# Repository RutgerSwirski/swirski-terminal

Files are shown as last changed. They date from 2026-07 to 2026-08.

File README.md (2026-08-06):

# Swirski Terminal

Swirski Terminal is a small wearable terminal built around an ESP32-S3,
an ILI9341 display, LVGL, and a rotary encoder. An Android companion app sends
notifications, media state, time, and Wi-Fi configuration over an encrypted
BLE connection.

The shared C++ application can also run as an SDL desktop build for faster UI
development and protocol testing.

## Current Features

- Notification snapshots, live notifications, detail views, and toasts
- Music state, progress, play/pause, previous, and next controls
- BLE pairing, bonding, chunked messages, and automatic reconnection
- Wi-Fi scanning, connection management, signal status, and internet testing
- Phone-synchronized date and time with persistent fallback
- Rotary encoder navigation, virtual keyboard, settings, and optional screen timeout
- Automatic Wi-Fi and BLE reconnection after transient disconnects
- Pong and Blackjack
- Shared LVGL screens and services across ESP32 and desktop targets

## Repository Layout

```text
app/      Shared C++ application, screens, services, protocol, and UI
desktop/  SDL/LVGL desktop simulator and C++ tests
esp32/    ESP-IDF firmware, hardware input, display, Wi-Fi, and BLE transport
mobile/   React Native Android companion app
docs/     Protocol documentation
```

## Desktop Build

Requirements:

- CMake 3.22 or newer
- Ninja
- A C++20 compiler
- SDL2 development files

Build and launch the simulator from the repository root:

```bash
./buildDesktop.sh
```

Run the C++ tests after building:

```bash
ctest --test-dir desktop/build --output-on-failure
```

## ESP32 Build

The firmware currently targets an ESP32-S3 with 4 MB flash, an ILI9341
320x240 SPI display, a rotary encoder, and a back button. Hardware pins are
defined near the top of `esp32/main/main.cpp` and in `esp32/main/inputs/`.
The display backlight uses an inverted BC327 PWM stage on GPIO 12. Brightness
can be adjusted from 10–100% in 10% steps in Settings, is retained across
restarts, and the backlight switches off with the display timeout.
The 30-second screen sleep can also be disabled in Settings to keep the display
on, and that choice is retained across restarts.
Settings also provides confirmed reboot and power-off actions. Power-off uses
ESP32 deep sleep because the current hardware has no software-controlled load
switch; press either the rotary knob or back button to start it again.

The MAX17048 fuel gauge is read at I2C address `0x36` every five seconds.
For the current direct-GPIO prototype, connect it as follows:

- MAX17048 SDA to ESP32-S3 GPIO 1
- MAX17048 SCL to ESP32-S3 GPIO 2
- MAX17048 VIN to 3.3 V and GND to GND

The two JST-PH battery sockets on the breakout are a pass-through pair: connect
the single-cell LiPo to either socket and the terminal's power/charging path to
the other. Battery voltage is retained in system state as millivolts, charge
percentage is shown in the status bar, and both readings are logged at debug
level. The PCB-v1 schematic instead reserves GPIO 8/9 for its shared I2C bus;
those pins must not be selected in this prototype firmware while the back and
encoder switches still use direct GPIO.

Install ESP-IDF, then build from the `esp32` directory:

```bash
source "$HOME/.espressif/v6.0.2/esp-idf/export.sh"
idf.py build
```

Flash and monitor a connected device:

```bash
idf.py -p /dev/ttyACM0 -b 115200 flash monitor
```

Change the serial port when your device appears under a different path.

Pushes to `main` that change `app/` or `esp32/` automatically build the
firmware and update the `firmware-latest` GitHub Release. The release asset is
published as `swirski_os_esp32.bin` for the terminal's OTA updater. The same
workflow can also be started manually from the GitHub Actions page.

## Android Companion

Requirements:

- Node.js 22.11 or newer
- Android Studio and the Android SDK
- A physical Android device with Bluetooth Low Energy

Install dependencies and start Metro:

```bash
cd mobile
npm install
npm start
```

In another terminal, install the debug app:

```bash
cd mobile
npm run android
```

Android notification-listener access is required for notification sync and
media discovery. The app prompts for the relevant Bluetooth and notification
permissions when needed.

Pushes to `main` that change `mobile/` automatically build the Android app and
replace the rolling `mobile-latest` GitHub Release. The app checks that
release's small manifest when it opens and shows **Mobile update available**
when its installed build number is older. The download opens in Android's
normal APK installation flow.

The rolling workflow requires the same permanent signing key for every build so
Android can install each APK over the previous one. Reuse and securely back up
the key that signed any APK already installed on your phone. Only generate a
new key if there is no existing release key:

```bash
keytool -genkeypair -v \
  -keystore swirski-upload.jks \
  -alias swirski-upload \
  -keyalg RSA \
  -keysize 2048 \
  -validity 10000
```

Configure these repository secrets before running the workflow, replacing the
example path with the existing key when applicable:

```bash
base64 -w 0 path/to/swirski-upload.jks | gh secret set SWIRSKI_UPLOAD_KEYSTORE_BASE64
gh secret set SWIRSKI_UPLOAD_STORE_PASSWORD
gh secret set SWIRSKI_UPLOAD_KEY_ALIAS
gh secret set SWIRSKI_UPLOAD_KEY_PASSWORD
```

Use the alias entered above (`swirski-upload` in the example). The last three
commands prompt for their values. Never commit the key or passwords. Losing
the key means future APKs cannot update existing installations.

Local standalone builds made by `mobile/deploy.sh` use Android's development
key unless the same `SWIRSKI_UPLOAD_*` environment variables are supplied. If
the app currently installed on a phone uses that development key, uninstall it
once before installing the first `mobile-latest` APK, then re-enable Android's
notification-listener access. Subsequent rolling releases install as updates.

## Protocol

Messages use a versioned JSON envelope. Larger BLE messages are divided into
frames and reassembled by the receiver. See
[`docs/ble-framing.md`](docs/ble-framing.md) for the framing format.

## License

This project is available under the [MIT License](LICENSE).

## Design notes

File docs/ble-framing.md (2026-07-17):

# Swirski BLE Framing

## Purpose

BLE can only send a limited number of bytes in a single write or notification.

Swirski protocol messages may be larger than this limit, especially notification messages containing titles, body text, or other data.

BLE framing splits one complete JSON message into smaller chunks before sending it.

The receiver then joins the chunks back together before passing the complete JSON to the Swirski protocol parser.

```text
JSON message
    ↓
UTF-8 bytes
    ↓
split into BLE frames
    ↓
send frames
    ↓
reassemble frames
    ↓
complete JSON message
```

The shared Swirski protocol should never receive partial chunks.

---

## Terminology

### Message

A complete UTF-8 JSON protocol message.

Example:

```json
{
  "version": 1,
  "type": "ping",
  "id": "mobile-123"
}
```

### Frame

One small BLE packet containing:

- A framing header
- A section of the complete message

### Transfer

The process of sending one complete message using one or more frames.

---

## Frame format

Each BLE frame begins with an eight-byte header.

| Bytes | Field | Type | Description |
| ----- | --- | --- | --- |
| 0 | Magic | `uint8` | Constant `0x53` |
| 1 | Frame version | `uint8` | Current value is `1` |
| 2–5 | Transfer ID | `uint32`  | Identifies the current transfer |
| 6 | Chunk index | `uint8` | Position of this chunk, starting at `0` |
| 7 | Chunk count | `uint8` | Total number of chunks in the transfer  |
| 8+ | Payload | Raw bytes | Part of the UTF-8 JSON message |

Multi-byte integers use little-endian byte order.

Example transfer ID:

```text
Transfer ID: 42
Hex value:   0x0000002A
Wire bytes:  2A 00 00 00
```

---

## Example

Assume a message is too large and must be split into two chunks.

The transfer ID is `42`.

### First frame

```text
53 01 2A 00 00 00 00 02 [first section of JSON]
│  │  │           │  │
│  │  │           │  └── total chunks: 2
│  │  │           └───── chunk index: 0
│  │  └───────────────── transfer ID: 42
│  └──────────────────── frame version: 1
└─────────────────────── magic byte: 0x53
```

### Second frame

```text
53 01 2A 00 00 00 01 02 [remaining section of JSON]
│  │  │           │  │
│  │  │           │  └── total chunks: 2
│  │  │           └───── chunk index: 1
│  │  └───────────────── transfer ID: 42
│  └──────────────────── frame version: 1
└─────────────────────── magic byte: 0x53
```

After both frames arrive, the receiver joins the payload bytes:

```text
first section + remaining section
```

The result is the original complete JSON message.

---

## Sending rules

For the first implementation:

1. Only one message is sent at a time in each direction.
2. Chunks are sent in order.
3. Chunk indexes start at `0`.
4. The sender waits for each BLE write to finish before sending the next chunk.
5. All chunks in one transfer use the same transfer ID.
6. All chunks in one transfer use the same chunk count.

Example:

```text
Send chunk 0
→ wait for write to finish
Send chunk 1
→ wait for write to finish
Transfer complete
```

Messages must not be interleaved.

Valid:

```text
Message A chunk 0
Message A chunk 1
Message B chunk 0
Message B chunk 1
```

Not supported initially:

```text
Message A chunk 0
Message B chunk 0
Message A chunk 1
Message B chunk 1
```

---

## Receiving rules

A received frame is grouped by BLE connection and transfer ID.

When a chunk arrives, the receiver stores:

- Transfer ID
- Expected chunk count
- Received payload bytes by chunk index
- Received payload byte count

Each chunk in the same transfer must have:

- The same chunk count
- A chunk index lower than the chunk count

Example:

```text
Received chunk: 1
→ store payload at index 1
```

If the chunk count changes:

```text
Expected chunks: 2
Received chunks: 3
→ reject and reset transfer
```

The message is complete when all chunk indexes from `0` to `chunk count - 1` have arrived.

Only then should the receiver:

1. Join all payload bytes in chunk-index order
2. Convert the bytes into a UTF-8 string
3. Pass the string to the shared protocol parser

```text
BLE frames
→ complete UTF-8 JSON
→ handleIncomingMessage()
```

---

## Chunk size

The maximum characteristic value size is approximately:

```text
negotiated MTU - 3
```

The Swirski framing header uses eight bytes.

Therefore:

```text
maximum chunk payload = negotiated MTU - 3 - 8
```

Example with an MTU of `128`:

```text
128 byte MTU
- 3 byte ATT overhead
- 8 byte Swirski frame header
= 117 message bytes per chunk
```

The exact negotiated MTU should be used when creating frames.

---

## Message encoding

Complete protocol messages use UTF-8 JSON.

The sender must:

```text
JSON string
→ UTF-8 bytes
→ split bytes into chunks
```

The receiver must:

```text
reassemble bytes
→ decode complete UTF-8 string
→ parse JSON
```

Chunks must be split by byte position, not by JavaScript character position.

This prevents multi-byte characters such as emoji from being damaged.

---

## Transfer ID

The BLE transfer ID is separate from the protocol message ID.

BLE transfer ID:

```text
Used to identify chunks belonging to one BLE transfer
```

Protocol message ID:

```json
{
  "id": "message-123"
}
```

The protocol ID cannot be used for framing because it is inside the JSON and is not available until the complete message has been reconstructed.

The transfer ID is a `uint32` value and wraps back to `1` after `4294967295`.

---

## Timeouts

Incomplete transfers must not remain in memory forever.

If no new chunk arrives within three seconds, the receiver discards the partial transfer.

```text
Chunk received
→ start or refresh timeout

No chunk for 3 seconds
→ reset transfer
```

A partial transfer should also be cleared when:

- The BLE connection closes
- The chunk count changes within an existing transfer
- The message exceeds the maximum allowed size

---

## Limits

Initial framing limits:

| Limit | Value |
| --- | --- |
| Header size | 8 bytes |
| Maximum chunks | 255 |
| Maximum complete message | 64 KiB |
| Incomplete transfer timeout | 3 seconds |
| Concurrent incoming transfers | By connection and transfer ID |

The practical maximum is also limited by the negotiated MTU because a complete
message may use at most 255 chunks.

---

## Direction

The same framing format is used in both directions.

### Phone to terminal

```text
React Native
→ split JSON into frames
→ write frames to RX characteristic
→ ESP32 reassembles message
```

### Terminal to phone

```text
ESP32
→ split JSON into frames
→ notify frames through TX characteristic
→ React Native reassembles message
```

Each direction maintains its own transfer state.

---

## Version 1 scope

The first version supports:

- Ordered chunks
- One outgoing transfer at a time
- UTF-8 JSON messages
- Transfer timeouts
- Maximum message size validation
- Framing in both directions

The first version does not include:

- Interleaved outgoing transfers
- Retransmission
- Checksums
- Compression
- Multiple simultaneous outgoing messages

These features can be added later if they become necessary.

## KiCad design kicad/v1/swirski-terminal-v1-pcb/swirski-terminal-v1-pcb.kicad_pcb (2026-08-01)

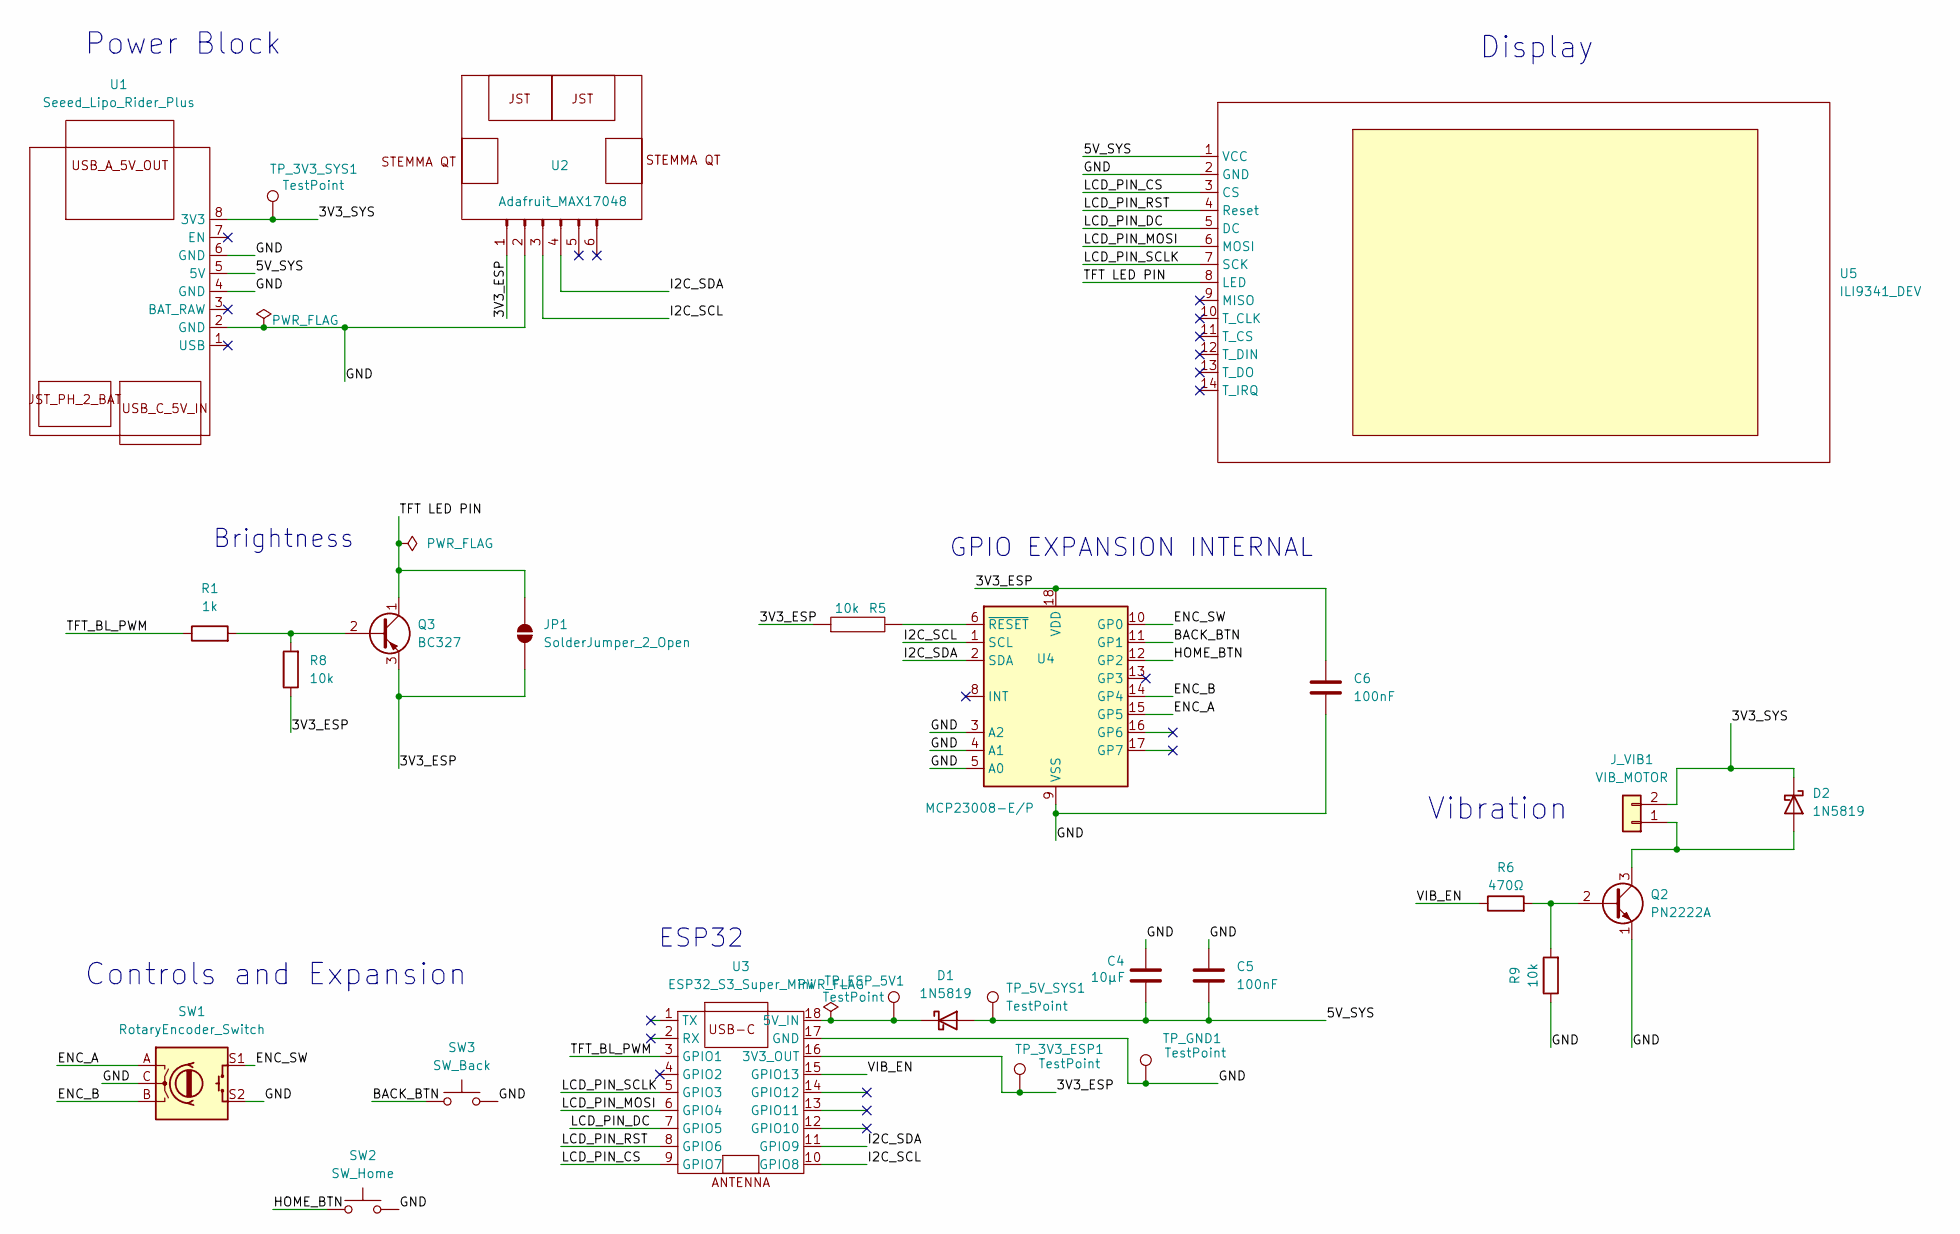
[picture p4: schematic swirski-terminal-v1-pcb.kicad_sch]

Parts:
C4: 10µF; CP_Radial_D5.0mm_P2.00mm
C5, C6: 100nF; C_Disc_D5.0mm_W2.5mm_P5.00mm
D1, D2: 1N5819; D_DO-41_SOD81_P10.16mm_Horizontal
JP1: SolderJumper_2_Open; PinHeader_1x02_P2.54mm_Vertical
J_VIB1: VIB_MOTOR; PinHeader_1x02_P2.54mm_Vertical
Q2: PN2222A; TO-92_Inline
Q3: BC327; TO-92_Inline
R1: 1k; R_Axial_DIN0207_L6.3mm_D2.5mm_P10.16mm_Horizontal
R5, R8, R9: 10k; R_Axial_DIN0207_L6.3mm_D2.5mm_P10.16mm_Horizontal
R6: 470Ω; R_Axial_DIN0207_L6.3mm_D2.5mm_P10.16mm_Horizontal
SW1: RotaryEncoder_Switch; RotaryEncoder_Alps_EC11E-Switch_Vertical_H20mm
SW2: SW_Home; SW_PUSH_6mm
SW3: SW_Back; SW_PUSH_6mm
TP_3V3_ESP1, TP_3V3_SYS1, TP_5V_SYS1: TestPoint; TestPoint_Loop_D2.50mm_Drill1.0mm
TP_ESP_5V1: TestPoint; TestPoint_Loop_D2.50mm_Drill1.0mm
TP_GND1: TestPoint; TestPoint_Loop_D2.50mm_Drill1.0mm
U1: Seeed_Lipo_Rider_Plus; Seeed_LiPo_Rider_Plus
U2: Adafruit_MAX17048; Adafruit_MAX17048_Breakout
U3: ESP32_S3_Super_Mini; ESP32_S3_SUPER_MINI_2x09Pins
U4: MCP23008-E/P; DIP-18_W7.62mm
U5: ILI9341_DEV; ILI9341_DEV_14Pin

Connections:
/3V3_ESP: C6.1, JP1.1 (A), Q3.3 (E), R5.1, R8.1, TP_3V3_ESP1.1 (1_1), U2.1 (VIN), U3.16 (3V3_OUT), U4.18 (VDD)
/3V3_SYS: D2.1 (K), J_VIB1.2, TP_3V3_SYS1.1 (1_1), U1.8 (3V3)
/5V_SYS: C4.2, C5.2, D1.2 (A), TP_5V_SYS1.1 (1_1), U1.5 (5V), U5.1 (VCC)
/BACK_BTN: SW3.1, U4.11 (GP1)
/ENC_A: SW1.A, U4.15 (GP5)
/ENC_B: SW1.B, U4.14 (GP4)
/ENC_SW: SW1.S1, U4.10 (GP0)
/EXTRA_GPIO_1: U4.13 (GP3)
/GND: C4.1, C5.1, C6.2, Q2.1 (E), R9.1, SW1.C, SW1.S2, SW2.2, SW3.2, TP_GND1.1 (1_1), U1.2 (GND), U1.4 (GND), U1.6 (GND), U2.2 (GND), U3.17 (GND), U4.3 (A2), U4.4 (A1), U4.5 (A0), U4.9 (VSS), U5.2 (GND)
/HOME_BTN: SW2.1, U4.12 (GP2)
/I2C_SCL: U2.3 (SCL), U3.10 (GPIO8), U4.1 (SCL)
/I2C_SDA: U2.4 (SDA), U3.11 (GPIO9), U4.2 (SDA)
/LCD_PIN_CS: U3.9 (GPIO7), U5.3 (CS)
/LCD_PIN_DC: U3.7 (GPIO5), U5.5 (DC)
/LCD_PIN_MOSI: U3.6 (GPIO4), U5.6 (MOSI)
/LCD_PIN_RST: U3.8 (GPIO6), U5.4 (Reset)
/LCD_PIN_SCLK: U3.5 (GPIO3), U5.7 (SCK)
/TFT LED PIN: JP1.2 (B), Q3.1 (C), U3.4 (GPIO2), U5.8 (LED)
/TFT_BL_PWM: R1.1, U3.3 (GPIO1)
/VIB_EN: R6.1, U3.15 (GPIO13)
unnamed: D1.1 (K), TP_ESP_5V1.1 (1_1), U3.18 (5V_IN)
unnamed: D2.2 (A), J_VIB1.1, Q2.3 (C)
unnamed: Q2.2 (B), R6.2, R9.2
unnamed: Q3.2 (B), R1.2, R8.2
unnamed: R5.2, U4.6 (~RESET)

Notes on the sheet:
Power Block
Controls and Expansion
Vibration
Display
ESP32
GPIO EXPANSION INTERNAL
Brightness

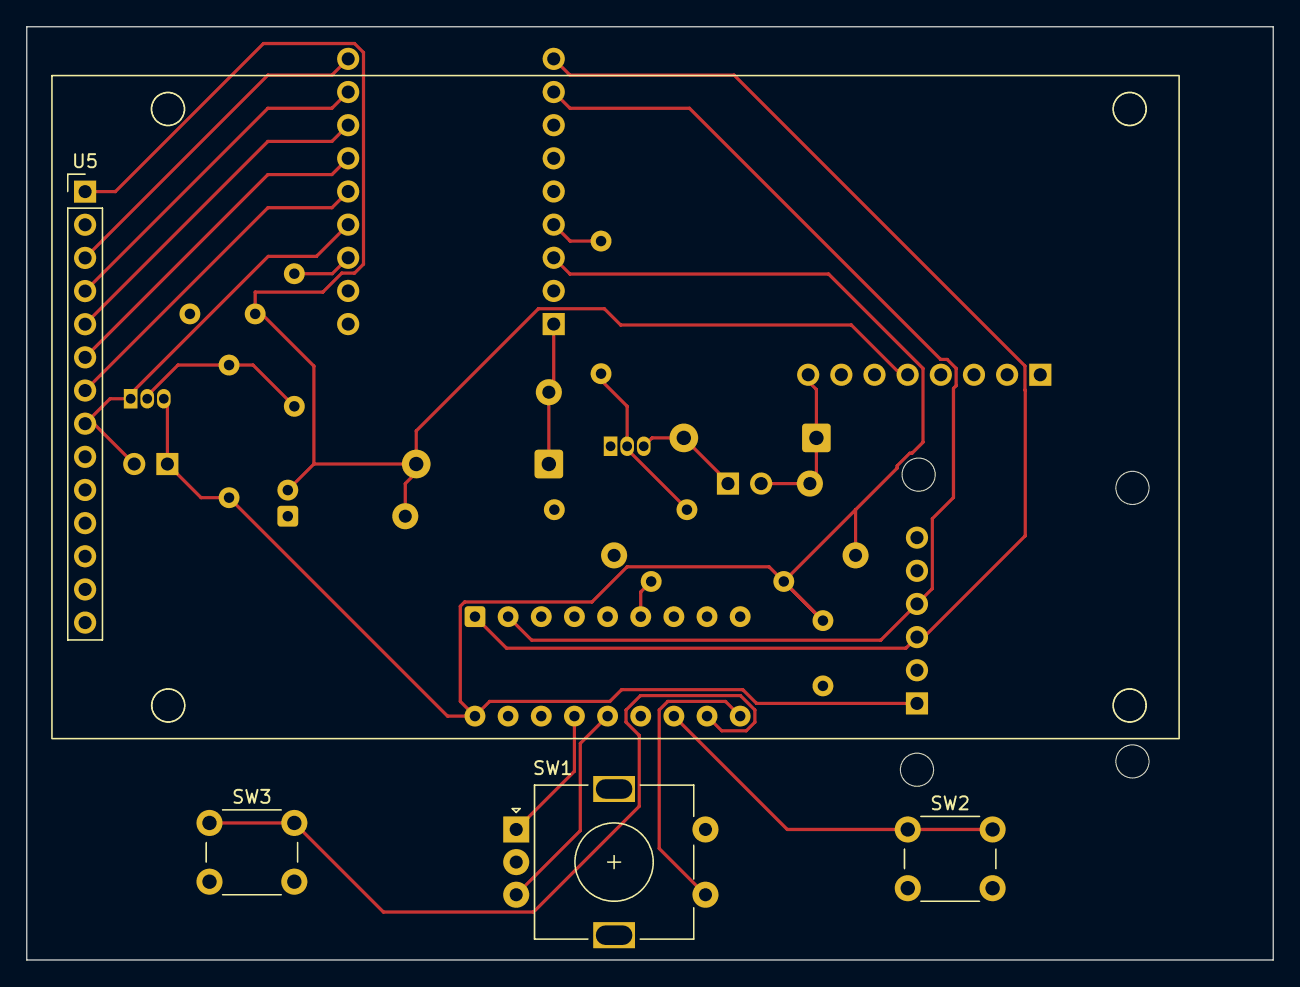
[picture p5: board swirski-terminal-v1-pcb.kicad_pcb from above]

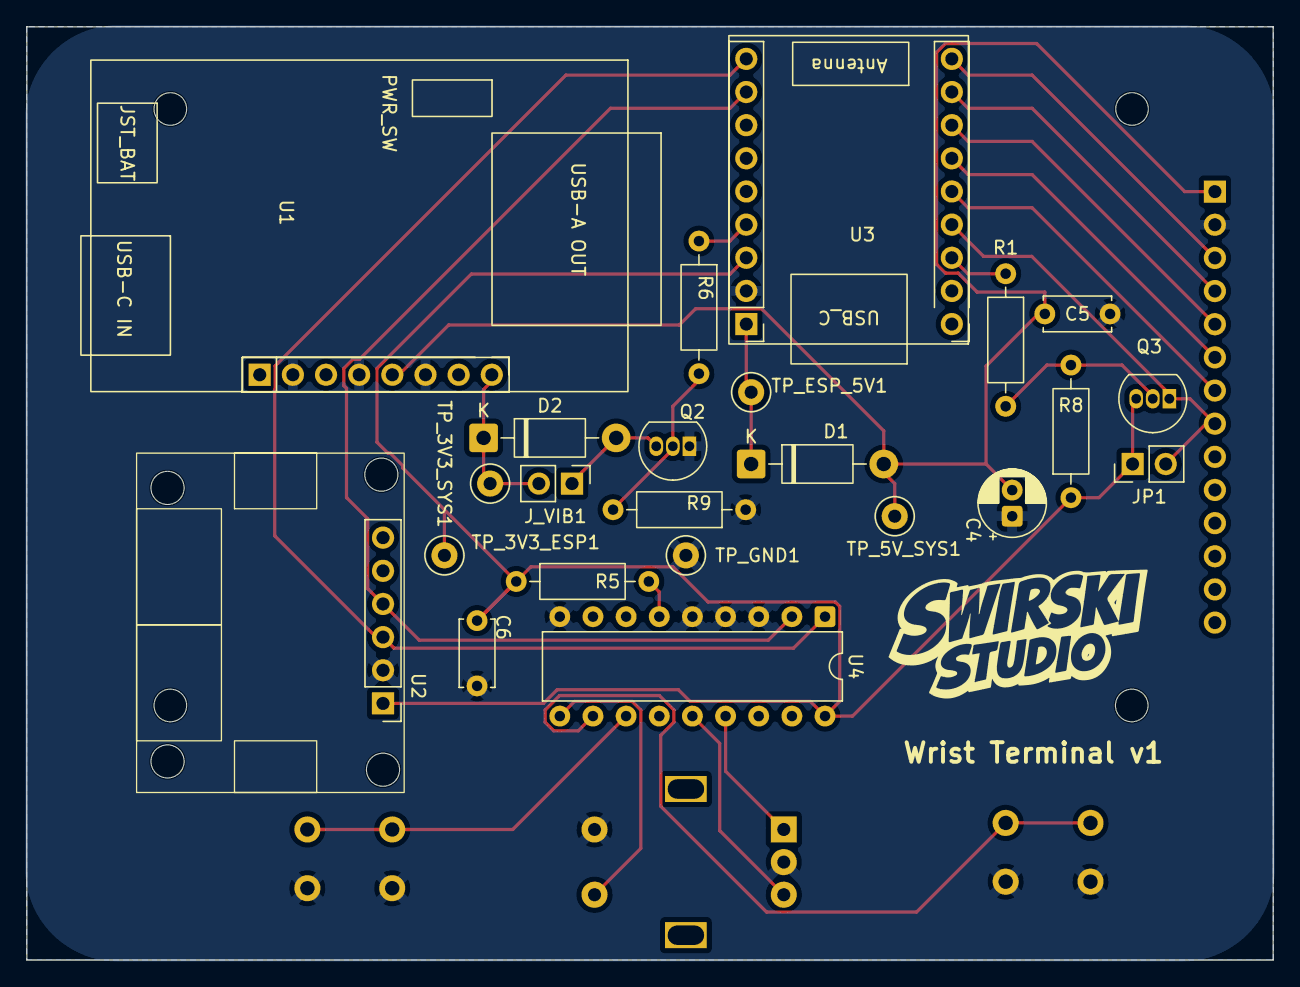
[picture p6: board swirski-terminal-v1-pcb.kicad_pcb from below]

Board: 2 copper layers, 95.5 x 71.5 mm, 27 parts (23 on the bottom side), 24 nets.

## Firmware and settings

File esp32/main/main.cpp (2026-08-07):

#include "driver/spi_master.h"
#include "esp_err.h"
#include "esp_lcd_panel_io.h"
#include "esp_lcd_panel_ops.h"
#include "esp_lcd_ili9341.h"
#include "esp_log.h"
#include "esp_lvgl_port.h"
#include "esp_sleep.h"
#include "esp_wifi.h"
#include "nvs_flash.h"
#include "freertos/FreeRTOS.h"
#include "freertos/task.h"
#include "lvgl.h"
#include "driver/gpio.h"

#include <cstdint>
#include <optional>

#include "app.hpp"
#include "./inputs/rotary_encoder.hpp"
#include "./inputs/push_buttons.hpp"
#include "haptics.hpp"
#include "app_constants.hpp"
#include "services/date_time.hpp"
#include "services/device_control.hpp"
#include "services/settings_service.hpp"
#include "services/firmware_update.hpp"
#include "screen_manager.hpp"
#include "settings_screen.hpp"
#include "notifications_screen.hpp"
#include "notification_screen.hpp"
#include "music_screen.hpp"
#include "weather_screen.hpp"
#include "ui/status_bar.hpp"
#include "ui/notification_toast.hpp"
#include "input.hpp"
#include "hardware_settings.hpp"
#include "wifi_service.hpp"
#include "wifi_screen.hpp"
#include "protocol.hpp"
#include "system_state.hpp"
#include "max17048.hpp"
#include "backlight.hpp"

#include "ble_transport.hpp"

namespace
{

    constexpr spi_host_device_t LCD_HOST = SPI2_HOST;

    constexpr gpio_num_t LCD_PIN_MOSI = GPIO_NUM_6;
    constexpr gpio_num_t LCD_PIN_SCLK = GPIO_NUM_7;
    constexpr gpio_num_t LCD_PIN_CS = GPIO_NUM_5;
    constexpr gpio_num_t LCD_PIN_DC = GPIO_NUM_4;
    constexpr gpio_num_t LCD_PIN_RST = GPIO_NUM_3;
    constexpr gpio_num_t BACK_BUTTON_PIN = GPIO_NUM_8;
    constexpr gpio_num_t ROTARY_BUTTON_PIN = GPIO_NUM_9;

    constexpr int LCD_WIDTH = 320;
    constexpr int LCD_HEIGHT = 240;

    lv_display_t *displayHandle = nullptr;
    esp_lcd_panel_handle_t panelHandle = nullptr;

    void setDisplayPower(bool on)
    {
        swirski::hardware::backlight::setEnabled(on);

        if (panelHandle != nullptr)
        {
            esp_lcd_panel_disp_on_off(
                panelHandle,
                on);
        }
    }

    void playNotificationHaptic()
    {
        swirski::hardware::haptics::play(
            swirski::hardware::haptics::Effect::Notification);
    }
}

void initialiseDisplay()
{
    constexpr size_t drawBufferHeight = 20;

    const size_t transferBufferSize =
        LCD_WIDTH *
        drawBufferHeight *
        sizeof(uint16_t);

    ESP_LOGI(swirski::TAG, "Initialising SPI bus");

    spi_bus_config_t busConfig{};

    busConfig.sclk_io_num = LCD_PIN_SCLK;
    busConfig.mosi_io_num = LCD_PIN_MOSI;
    busConfig.miso_io_num = -1;
    busConfig.quadwp_io_num = -1;
    busConfig.quadhd_io_num = -1;
    busConfig.max_transfer_sz =
        static_cast<int>(transferBufferSize);

    ESP_ERROR_CHECK(
        spi_bus_initialize(
            LCD_HOST,
            &busConfig,
            SPI_DMA_CH_AUTO));

    ESP_LOGI(swirski::TAG, "Creating LCD SPI interface");

    esp_lcd_panel_io_handle_t ioHandle = nullptr;

    esp_lcd_panel_io_spi_config_t ioConfig{};

    ioConfig.cs_gpio_num = LCD_PIN_CS;
    ioConfig.dc_gpio_num = LCD_PIN_DC;
    ioConfig.spi_mode = 0;
    ioConfig.pclk_hz = 40 * 1000 * 1000;
    ioConfig.trans_queue_depth = 10;
    ioConfig.lcd_cmd_bits = 8;
    ioConfig.lcd_param_bits = 8;

    ESP_ERROR_CHECK(
        esp_lcd_new_panel_io_spi(
            static_cast<esp_lcd_spi_bus_handle_t>(LCD_HOST),
            &ioConfig,
            &ioHandle));

    ESP_LOGI(swirski::TAG, "Creating ILI9341 panel");

    esp_lcd_panel_dev_config_t panelConfig{};

    panelConfig.reset_gpio_num = LCD_PIN_RST;
    panelConfig.rgb_ele_order = LCD_RGB_ELEMENT_ORDER_BGR;
    panelConfig.bits_per_pixel = 16;

    ESP_ERROR_CHECK(
        esp_lcd_new_panel_ili9341(
            ioHandle,
            &panelConfig,
            &panelHandle));

    ESP_ERROR_CHECK(esp_lcd_panel_reset(panelHandle));
    ESP_ERROR_CHECK(esp_lcd_panel_init(panelHandle));
    ESP_ERROR_CHECK(esp_lcd_panel_disp_on_off(panelHandle, true));

    ESP_LOGI(swirski::TAG, "Registering display with LVGL");

    lvgl_port_display_cfg_t displayConfig{};

    displayConfig.io_handle = ioHandle;
    displayConfig.panel_handle = panelHandle;
    displayConfig.buffer_size = LCD_WIDTH * drawBufferHeight;
    displayConfig.double_buffer = false;
    displayConfig.hres = LCD_WIDTH;
    displayConfig.vres = LCD_HEIGHT;
    displayConfig.monochrome = false;

    displayConfig.rotation.swap_xy = true;
    displayConfig.rotation.mirror_x = true;
    displayConfig.rotation.mirror_y = true;

    displayConfig.color_format = LV_COLOR_FORMAT_RGB565;

    displayConfig.flags.buff_dma = true;
    displayConfig.flags.swap_bytes = true;

    displayHandle = lvgl_port_add_disp(&displayConfig);

    if (displayHandle == nullptr)
    {
        ESP_LOGE(swirski::TAG, "Could not register display with LVGL");
        return;
    }

    ESP_LOGI(swirski::TAG, "Display initialised");
}

// use C linkage
extern "C" void app_main()
{
    ESP_LOGI(swirski::TAG, "Starting Swirski OS");

    swirski::hardware::backlight::initialise();

    esp_err_t nvsResult =
        nvs_flash_init();

    if (
        nvsResult == ESP_ERR_NVS_NO_FREE_PAGES ||
        nvsResult == ESP_ERR_NVS_NEW_VERSION_FOUND)
    {
        ESP_ERROR_CHECK(
            nvs_flash_erase());

        nvsResult =
            nvs_flash_init();
    }

    ESP_ERROR_CHECK(nvsResult);

    const lvgl_port_cfg_t lvglConfig =
        ESP_LVGL_PORT_INIT_CONFIG();

    ESP_ERROR_CHECK(
        lvgl_port_init(&lvglConfig));

    vTaskDelay(1);

    initialiseDisplay();

    swirski::screens::manager::setDisplayPowerHandler(
        setDisplayPower);

    swirski::service::settings::initialise();
    swirski::settings::hardware::initialise();
    swirski::services::wifi_service::initialise();

    vTaskDelay(1);

    swirski::inputs::rotary_encoder::initialise();
    swirski::inputs::push_buttons::initialise();

    swirski::hardware::haptics::initialise();
    swirski::hardware::max17048::initialise();

    swirski::service::date_time::initialise(0);

    swirski::transport::ble::BleTransport bleTransport;

    bleTransport.initialise();
    swirski::services::device_control::setRestartHandler(
        [&bleTransport]()
        {
            bleTransport.disconnectAll();
            vTaskDelay(pdMS_TO_TICKS(250));
            esp_restart();
        });
    swirski::services::device_control::setPowerOffHandler(
        [&bleTransport]()
        {
            bleTransport.disconnectAll();
            setDisplayPower(false);
            esp_wifi_stop();

            while (
                gpio_get_level(BACK_BUTTON_PIN) == 0 ||
                gpio_get_level(ROTARY_BUTTON_PIN) == 0)
            {
                vTaskDelay(pdMS_TO_TICKS(10));
            }

            const std::uint64_t wakeButtonMask =
                (1ULL << BACK_BUTTON_PIN) |
                (1ULL << ROTARY_BUTTON_PIN);

            ESP_ERROR_CHECK(
                esp_sleep_enable_ext1_wakeup_io(
                    wakeButtonMask,
                    ESP_EXT1_WAKEUP_ANY_LOW));

            vTaskDelay(pdMS_TO_TICKS(250));
            esp_deep_sleep_start();
        });
    swirski::services::firmware_update::setBeforeRestartHandler(
        [&bleTransport]()
        {
            bleTransport.disconnectAll();
        });
    swirski::screens::music_screen::setTransport(
        &bleTransport);

    vTaskDelay(1);

    if (lvgl_port_lock(0))
    {
        swirski::app::createInterface(displayHandle);

        swirski::ui::status_bar::updateClock();

        lvgl_port_unlock();
    }

    swirski::services::firmware_update::confirmRunningFirmware();

    vTaskDelay(1);

    bool wifiScanInProgress = false;
    auto lastWifiState =
        swirski::services::wifi_service::getConnectionState();
    auto lastInternetTestState =
        swirski::services::wifi_service::getInternetTestState();
    std::optional<std::uint8_t> lastSentBatteryPercent;
    bool lastSentCharging = false;
    bool batteryStatusSent = false;

    swirski::services::notification_service::setAlertHandler(
        playNotificationHaptic);

    while (true)
    {

        bleTransport.update();
        swirski::services::wifi_service::update();
        swirski::hardware::max17048::update();

        const auto systemSnapshot =
            swirski::state::system::getSnapshot();

        if (
            systemSnapshot.connection.status !=
            swirski::state::system::ConnectionStatus::Connected)
        {
            batteryStatusSent = false;
        }
        else if (
            !batteryStatusSent ||
            systemSnapshot.batteryPercent !=
                lastSentBatteryPercent ||
            systemSnapshot.charging != lastSentCharging)
        {
            bleTransport.send(
                swirski::protocol::createBatteryStatusMessage());

            lastSentBatteryPercent =
                systemSnapshot.batteryPercent;
            lastSentCharging =
                systemSnapshot.charging;
            batteryStatusSent = true;
        }

        const bool wifiScanning =
            swirski::services::wifi_service::isScanning();
        const auto wifiState =
            swirski::services::wifi_service::getConnectionState();
        const auto internetTestState =
            swirski::services::wifi_service::getInternetTestState();
        bool wifiStatusSent = false;

        if (wifiScanning)
        {
            wifiScanInProgress = true;
        }
        else if (wifiScanInProgress)
        {
            wifiScanInProgress = false;
            bleTransport.send(
                swirski::protocol::createWifiNetworksMessage());
            bleTransport.send(
                swirski::protocol::createWifiStatusMessage());
            wifiStatusSent = true;
        }

        if (wifiState != lastWifiState)
        {
            lastWifiState = wifiState;

            if (!wifiStatusSent)
            {
                bleTransport.send(
                    swirski::protocol::createWifiStatusMessage());
            }
        }

        if (internetTestState != lastInternetTestState)
        {
            lastInternetTestState = internetTestState;

            if (
                internetTestState ==
                    swirski::services::wifi_service::InternetTestState::Success ||
                internetTestState ==
                    swirski::services::wifi_service::InternetTestState::Failed)
            {
                bleTransport.send(
                    swirski::protocol::createWifiStatusMessage());
            }
        }

        if (lvgl_port_lock(0))
        {
            swirski::ui::status_bar::updateSystemState();
            swirski::ui::notification_toast::update();
            swirski::screens::manager::updatePowerState();

            if (
                swirski::screens::manager::getCurrentScreen() ==
                swirski::screens::manager::Screen::Notifications)
            {
                swirski::screens::notifications_screen::
                    refreshIfNeeded();
            }

            if (
                swirski::screens::manager::getCurrentScreen() ==
                swirski::screens::manager::Screen::Notification)
            {
                swirski::screens::notification_screen::
                    refreshIfNeeded();
            }

            if (
                swirski::screens::manager::getCurrentScreen() ==
                swirski::screens::manager::Screen::Music)
            {
                swirski::screens::music_screen::
                    refreshIfNeeded();
            }

            if (
                swirski::screens::manager::getCurrentScreen() ==
                swirski::screens::manager::Screen::Weather)
            {
                swirski::screens::weather_screen::refreshIfNeeded();
            }

            if (
                swirski::screens::manager::getCurrentScreen() ==
                swirski::screens::manager::Screen::Wifi)
            {
                swirski::screens::wifi_screen::refreshIfNeeded();
            }

            if (
                swirski::screens::manager::getCurrentScreen() ==
                swirski::screens::manager::Screen::Settings)
            {
                swirski::screens::settings_screen::refreshIfNeeded();
            }

            lvgl_port_unlock();
        }

        swirski::inputs::rotary_encoder::poll();

        swirski::hardware::haptics::update();

        if (swirski::inputs::push_buttons::backPressed())
        {
            ESP_LOGI(swirski::TAG, "Back button pressed");

            if (lvgl_port_lock(20))
            {
                const bool screenWoke =
                    swirski::screens::manager::wake();

                const bool toastDismissed =
                    !screenWoke &&
                    swirski::ui::notification_toast::dismiss();

                if (!screenWoke && !toastDismissed)
                {
                    swirski::input::handleInput(
                        swirski::input::input_action::Back);
                }

                lvgl_port_unlock();
            }
        }

        if (swirski::service::date_time::update())
        {
            if (lvgl_port_lock(20))
            {
                swirski::ui::status_bar::updateClock();
                lvgl_port_unlock();
            }
        }

        vTaskDelay(1);
    }
}

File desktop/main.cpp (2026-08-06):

#define SDL_MAIN_HANDLED

#include "lvgl.h"
#include "app.hpp"

#include <SDL2/SDL.h>

#include <iostream>

#include "inputs/keyboard.hpp"

#include "services/date_time.hpp"

#include "ui/status_bar.hpp"

#include <chrono>

#include <ctime>

#include "websocket_transport.hpp"
#include "music_screen.hpp"
#include "weather_screen.hpp"
#include "notifications_screen.hpp"
#include "notification_screen.hpp"
#include "screen_manager.hpp"
#include "settings_screen.hpp"
#include "wifi_screen.hpp"

int main()

{

    SDL_Event event;

    bool running = true;

    lv_init();

    lv_display_t *display =
        lv_sdl_window_create(320, 240);

    lv_sdl_window_set_zoom(display, 2.0f);

    if (display == nullptr)
    {
        return 1;
    }

    lv_display_set_default(display);

    lv_sdl_mouse_create();
    lv_sdl_mousewheel_create();
    lv_sdl_keyboard_create();

    swirski::app::createInterface(display);

    const auto now = std::chrono::system_clock::now();

    const std::time_t currentTime =
        std::chrono::system_clock::to_time_t(now);

    swirski::service::date_time::initialise(currentTime);
    swirski::ui::status_bar::updateClock();

    swirski::transport::websocket::WebSocketTransport websocketTransport;

    // initialise transport websocket
    websocketTransport.initialise();
    swirski::screens::music_screen::setTransport(
        &websocketTransport);

    while (running)
    {

        websocketTransport.update();
        swirski::ui::status_bar::updateSystemState();

        switch (swirski::screens::manager::getCurrentScreen())
        {
        case swirski::screens::manager::Screen::Notifications:
            swirski::screens::notifications_screen::refreshIfNeeded();
            break;
        case swirski::screens::manager::Screen::Notification:
            swirski::screens::notification_screen::refreshIfNeeded();
            break;
        case swirski::screens::manager::Screen::Music:
            swirski::screens::music_screen::refreshIfNeeded();
            break;
        case swirski::screens::manager::Screen::Weather:
            swirski::screens::weather_screen::refreshIfNeeded();
            break;
        case swirski::screens::manager::Screen::Wifi:
            swirski::screens::wifi_screen::refreshIfNeeded();
            break;
        case swirski::screens::manager::Screen::Settings:
            swirski::screens::settings_screen::refreshIfNeeded();
            break;
        default:
            break;
        }

        swirski::inputs::keyboard::processInput(event, running);

        const bool time_changed = swirski::service::date_time::update();

        if (time_changed)
        {
            swirski::ui::status_bar::updateClock();
        }

        lv_timer_handler();
        lv_delay_ms(5);
    }

    return 0;
}

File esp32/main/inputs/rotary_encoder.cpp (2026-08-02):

// ESP32 rotary encoder GPIO setup and input decoding
#include "driver/gpio.h"
#include "driver/pulse_cnt.h"
#include "esp_log.h"
#include "esp_lvgl_port.h"

#include <cstdint>

#include "rotary_encoder.hpp"
#include "app_constants.hpp"
#include "input.hpp"
#include "haptics.hpp"

namespace swirski::inputs::rotary_encoder
{

    namespace
    {
        constexpr gpio_num_t ROTARY_PIN_A = GPIO_NUM_11;
        constexpr gpio_num_t ROTARY_PIN_B = GPIO_NUM_10;
        constexpr gpio_num_t ROTARY_SWITCH = GPIO_NUM_9;

        constexpr int PCNT_LOW_LIMIT = -32'767;
        constexpr int PCNT_HIGH_LIMIT = 32'767;
        constexpr int PULSES_PER_DETENT = 4;
        constexpr int MAX_PENDING_DETENTS = 4;
        constexpr std::uint32_t PCNT_GLITCH_FILTER_NS = 10'000;

        pcnt_unit_handle_t pcntUnit = nullptr;
        pcnt_channel_handle_t pcntChannelA = nullptr;
        pcnt_channel_handle_t pcntChannelB = nullptr;

        int previousPulseCount = 0;
        int pendingPulseCount = 0;
        int prevSwitch = 0;

        bool dispatchInput(
            swirski::input::input_action action,
            const char *message)
        {
            if (!lvgl_port_lock(20))
            {
                return false;
            }

            ESP_LOGD(swirski::TAG, "%s", message);

            swirski::input::handleInput(action);

            lvgl_port_unlock();

            swirski::hardware::haptics::play(
                swirski::hardware::haptics::Effect::Tick);

            return true;
        }

    }

    void initialise()
    {
        ESP_LOGI(swirski::TAG, "Initialising rotary encoder");

        gpio_config_t rotaryConfig{};

        rotaryConfig.pin_bit_mask =
            (1ULL << ROTARY_PIN_A) |
            (1ULL << ROTARY_PIN_B) |
            (1ULL << ROTARY_SWITCH);

        rotaryConfig.mode = GPIO_MODE_INPUT;
        rotaryConfig.pull_up_en = GPIO_PULLUP_ENABLE;
        rotaryConfig.pull_down_en = GPIO_PULLDOWN_DISABLE;
        rotaryConfig.intr_type = GPIO_INTR_DISABLE;

        ESP_ERROR_CHECK(gpio_config(&rotaryConfig));

        pcnt_unit_config_t unitConfig{};
        unitConfig.low_limit = PCNT_LOW_LIMIT;
        unitConfig.high_limit = PCNT_HIGH_LIMIT;

        ESP_ERROR_CHECK(
            pcnt_new_unit(
                &unitConfig,
                &pcntUnit));

        pcnt_glitch_filter_config_t glitchFilterConfig{};
        glitchFilterConfig.max_glitch_ns =
            PCNT_GLITCH_FILTER_NS;

        ESP_ERROR_CHECK(
            pcnt_unit_set_glitch_filter(
                pcntUnit,
                &glitchFilterConfig));

        pcnt_chan_config_t channelAConfig{};
        channelAConfig.edge_gpio_num = ROTARY_PIN_A;
        channelAConfig.level_gpio_num = ROTARY_PIN_B;

        ESP_ERROR_CHECK(
            pcnt_new_channel(
                pcntUnit,
                &channelAConfig,
                &pcntChannelA));

        pcnt_chan_config_t channelBConfig{};
        channelBConfig.edge_gpio_num = ROTARY_PIN_B;
        channelBConfig.level_gpio_num = ROTARY_PIN_A;

        ESP_ERROR_CHECK(
            pcnt_new_channel(
                pcntUnit,
                &channelBConfig,
                &pcntChannelB));

        ESP_ERROR_CHECK(
            pcnt_channel_set_edge_action(
                pcntChannelA,
                PCNT_CHANNEL_EDGE_ACTION_DECREASE,
                PCNT_CHANNEL_EDGE_ACTION_INCREASE));

        ESP_ERROR_CHECK(
            pcnt_channel_set_level_action(
                pcntChannelA,
                PCNT_CHANNEL_LEVEL_ACTION_KEEP,
                PCNT_CHANNEL_LEVEL_ACTION_INVERSE));

        ESP_ERROR_CHECK(
            pcnt_channel_set_edge_action(
                pcntChannelB,
                PCNT_CHANNEL_EDGE_ACTION_INCREASE,
                PCNT_CHANNEL_EDGE_ACTION_DECREASE));

        ESP_ERROR_CHECK(
            pcnt_channel_set_level_action(
                pcntChannelB,
                PCNT_CHANNEL_LEVEL_ACTION_KEEP,
                PCNT_CHANNEL_LEVEL_ACTION_INVERSE));

        ESP_ERROR_CHECK(
            pcnt_unit_enable(pcntUnit));

        ESP_ERROR_CHECK(
            pcnt_unit_clear_count(pcntUnit));

        ESP_ERROR_CHECK(
            pcnt_unit_start(pcntUnit));

        previousPulseCount = 0;
        pendingPulseCount = 0;
        prevSwitch = gpio_get_level(ROTARY_SWITCH);

        ESP_LOGI(swirski::TAG, "Rotary encoder initialised");
    }

    void poll()
    {
        int pulseCount = 0;

        ESP_ERROR_CHECK(
            pcnt_unit_get_count(
                pcntUnit,
                &pulseCount));

        int pulseDelta =
            pulseCount -
            previousPulseCount;

        if (pulseDelta > PCNT_HIGH_LIMIT / 2)
        {
            pulseDelta -= PCNT_HIGH_LIMIT;
        }
        else if (pulseDelta < PCNT_LOW_LIMIT / 2)
        {
            pulseDelta -= PCNT_LOW_LIMIT;
        }

        pendingPulseCount += pulseDelta;

        const int maxPendingPulses =
            PULSES_PER_DETENT *
            MAX_PENDING_DETENTS;

        if (pendingPulseCount > maxPendingPulses)
        {
            pendingPulseCount = maxPendingPulses;
        }
        else if (pendingPulseCount < -maxPendingPulses)
        {
            pendingPulseCount = -maxPendingPulses;
        }

        previousPulseCount = pulseCount;

        if (pendingPulseCount >= PULSES_PER_DETENT)
        {
            if (dispatchInput(
                    swirski::input::input_action::Next,
                    "NEXT"))
            {
                pendingPulseCount -= PULSES_PER_DETENT;
            }
        }
        else if (pendingPulseCount <= -PULSES_PER_DETENT)
        {
            if (dispatchInput(
                    swirski::input::input_action::Previous,
                    "PREVIOUS"))
            {
                pendingPulseCount += PULSES_PER_DETENT;
            }
        }

        const int currentSwitch = gpio_get_level(ROTARY_SWITCH);

        // Detect the button changing from not pressed to pressed.
        if (prevSwitch == 1 && currentSwitch == 0)
        {
            dispatchInput(
                swirski::input::input_action::Confirm,
                "CONFIRM");
        }

        prevSwitch = currentSwitch;
    }
}

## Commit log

2026-07-11 added rotary encoder and clean build and flash to esp32
2026-07-11 setup rotary encoder logic!
2026-07-11 rotary encoder working!
2026-07-14 Add push buttons input handling: implement initialization and back button press detection; update main and CMakeLists to integrate functionality
2026-07-15 Add ArduinoJson dependency and implement message handling in protocol
2026-07-16 Enhance Bluetooth connection handling: add connection status management and improve device connection logic
2026-07-16 Add locking mechanism around status bar update to ensure thread safety
2026-07-17 Refactor BLE message framing: update header structure, implement frame assembler, and enhance message handling
2026-07-17 Add frame queuing and sending mechanism in BLE transport
2026-07-17 Implement time synchronization feature: add TimeSync message type and send current date/time from mobile app
2026-07-17 Refactor BLE frame logging: introduce shouldLogFrameProgress function for consistent logging and update notification toast duration to 4500ms
2026-07-17 Refactor UI components: enhance ConnectionPanel, DebugActions, and DeviceList with Card components and improve layout in TerminalScreen
2026-07-17 Add settings screen and power management: implement settings UI, input handling, and power mode management
2026-07-18 Filter devices based on connection status: show only connected device when one is selected
2026-07-18 Persist time and power settings
2026-07-18 Expand ESP32 application partition
    [partitions.csv]
2026-07-18 Add ESP32 Wi-Fi setup flow
2026-07-18 Implement send retry mechanism for BLE frames and update SDK configuration
2026-07-18 Configure dual-slot OTA rollback
    [partitions.csv]
2026-07-19 Refactor Snake and Tetris screens for improved memory management and game logic
    - Introduced lazy allocation of board buffers in both Snake and Tetris screens to optimize memory usage.
    - Added functions to allocate, pause, and resume game timers for better control over game state.
    - Enhanced collision detection logic in Snake to prevent game over when the snake eats food.
    - Improved food placement logic in Snake to avoid infinite loops when the board is nearly full.
    - Updated drawing functions to ensure proper rendering of game elements.
    - Refactored game initialization and cleanup processes to ensure proper resource management.
    - Added error handling for memory allocation failures in both g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
2026-07-23 Enhance Snake and Tetris screens for ESP32 compatibility and memory management
2026-07-26 Add initial files for Swirski Terminal PCB project
    - Created fp-lib-table for footprint library management.
    - Added main PCB file (swirski-terminal-v1-pcb.kicad_pcb) with versioning.
    - Included project settings in swirski-terminal-v1-pcb.kicad_prl.
    - Established design settings and rules in swirski-terminal-v1-pcb.kicad_pro.
    - Created schematic file (swirski-terminal-v1-pcb.kicad_sch) with basic structure.
    - Added symbol library table (sym-lib-table) for component management.
    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
    [swirski-terminal-v1-pcb.kicad_pcb, swirski-terminal-v1-pcb.kicad_sch]
2026-07-27 Add Swirski_Terminal library to symbol library table
    [swirski-terminal-v1-pcb.kicad_sch]
2026-07-27 updated swirski terminal schematic!
    [swirski-terminal-v1-pcb.kicad_sch]
2026-07-28 PCB Updates
    [swirski-terminal-v1-pcb.kicad_sch]
2026-07-29 More Kicad updates - playing around with the schematic and replacing SMD components that were being used on the PCB
    [swirski-terminal-v1-pcb.kicad_pcb, swirski-terminal-v1-pcb.kicad_sch]
2026-08-01 Add lock file for KiCad schematic to prevent concurrent edits
    [swirski-terminal-v1-pcb-B_Cu.gbr, swirski-terminal-v1-pcb-B_Mask.gbr, swirski-terminal-v1-pcb-B_Paste.gbr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]
2026-08-02 feat(rotary_encoder): enhance rotary encoder input handling with pulse counter and dispatch logic
2026-08-02 feat(haptics): enhance haptic feedback with notification phases and motor control
2026-08-03 chore(kicad): keep local history out of repository
2026-08-04 feat(battery): integrate MAX17048 fuel gauge for battery monitoring
2026-08-06 fix(notifications): refresh open notification details
    [main.cpp]
2026-08-06 feat(power): add reboot and deep-sleep controls
    [main.cpp]
2026-08-06 docs: describe reconnect and power controls
2026-08-07 feat(battery): publish terminal status over BLE
2026-08-07 feat(mobile): show terminal battery level
2026-08-07 chore(kicad): refresh project metadata
